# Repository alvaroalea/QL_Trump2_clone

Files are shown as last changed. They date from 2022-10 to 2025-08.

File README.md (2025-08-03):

# SINCLAIR QL Trump Card V2 disk interface

(C) 2022 Alvaro Alea Fernandez

License under: CERN Open Hardware Licence Version 2 - Strongly Reciprocal

https://ohwr.org/cern_ohl_s_v2.txt

Available in the market in 4 ways, 0K, 256Kb/ACE, 512Kb, 768Kb and Treo (256Kb aditional).

Only 0Kb has been tested.

Check the readme in the GAL folder, up to now, I only be able to make it work without RAM.

# Technical Info

## Components to use

### 4040
We found that not all manufacturer made CD4040 or 74HC4040 in the same way, and some made counter with rise-edge of clock, and some with falling-edge.

The trump card need falling edge or will mess with the refresh cycle and do not work.

The eprom/gal programer TL-866 II+ has a function to test TLL chips, but fail to detect it and consider valid both variants.

We have include the file 4040-test.lgc with a custom test that when load on the programmer allow to detect valid 74HC4040 variants. (best to use 74HC4040 that CD4040)

### RAM Chips
Trump Card use 514256 Ram chips, this is 4bits x 256K (1Mbit) Dinamic RAM.

Trump Card use a special refresh mode of this chips called hidden refresh, but not all manufacturer implement in tha same way.

Has been reported that Texas Instrument TMS44C256 are not valid and will cause errors on boot.

Motorola (MCM514256) Siemens (HYB514256) and OKI (MSM514256) has been reported to work

Toshiba (TC514256) and GoldStart (GM71C4256) al also valid acording to datasheet, but not tested.

The trump card schematic used 0 wait state ram, even in the refresh cycle, and for that speed of the dram shall be between 70 and 100ns, 120ns or slower are not valid.

HOLD

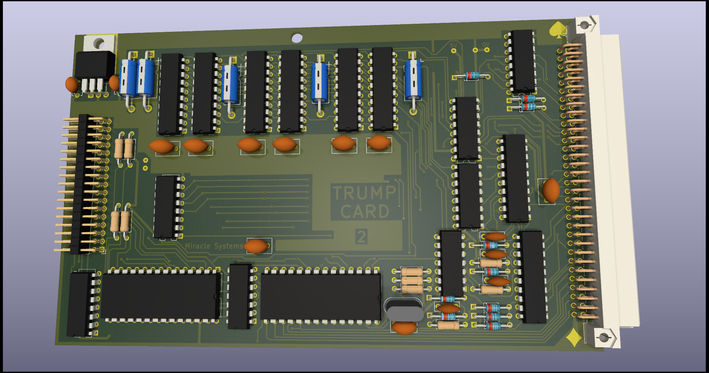
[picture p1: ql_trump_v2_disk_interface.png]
 

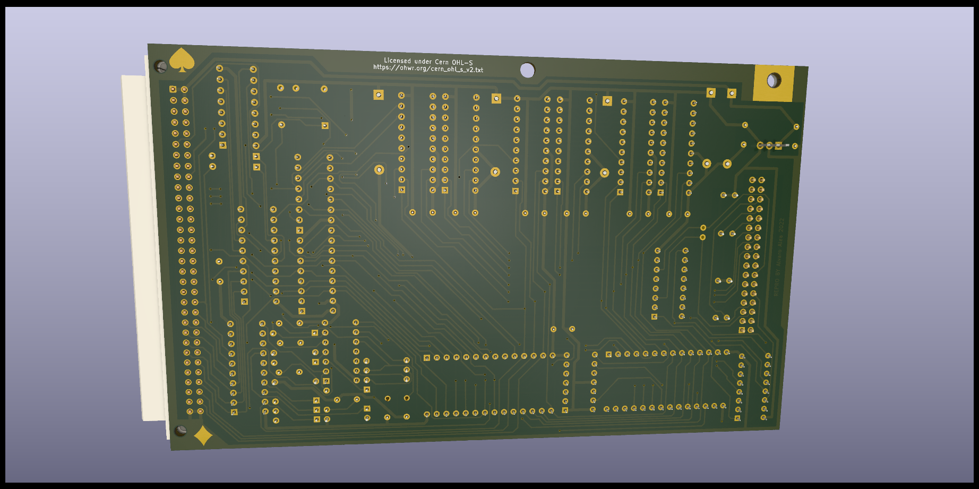
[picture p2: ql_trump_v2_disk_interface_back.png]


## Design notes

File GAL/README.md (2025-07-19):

# GAL Equations and JEDEC files

Trump Card contains 2 programable logic chips for several functions:
* Chip 1 is in charge of the I/O and Rom mapping, incorporate the mechanism to pagged in and out ROM and RAM in 0xC0000 on boot to allow JS ROM to start.
* Chip 2 is in charge of the RAS/CAS generation and other signals for the RAM chips.

In the original cards, both chips are of type PAL16L8, that is obsolete nowdays.

There is only 1 version of the Chip 1, and have a sticker with "1V4"

There is 2 diferent version of Chip 1, one for Trump Card 1 (with 24 RAM chips) labeled "2V2" and another for Trump Card 2 (6 RAM chips) labeled "2V4"

## Tetroid

This directory there is the equations shared by Tetroid and others in several places of internet.

Chip 1 is know to work if burn in a GAL16V8 chip, included JED files of the TC1, TC2 and Tetroid version, that are equal when disasembled.

Chip 2 for TC1 include dump and GALASM source.

Chip 2 for TC2 include JED for GAL and PAL, but is know that only the PAL work.

## only_minerva

My own version of the equations of the chip 1, intended to be used in a board without RAM with external RAM expansion.

This version only work with Minerva ROM, because it lack the pagging mechanism needed to boot in a JS ROM, this version is save to use with 768Kb external expansion, to achive the 892Kb (maximun RAM in a QL)

Include the Winculp source.

## wip

The Work-In-Progress ecuations

Chip 1 version with the pagging mechanish that work in JS and Minerva Roms. Miracle sell serveral version of the card with diferent memory configurations, its not clear if the ecuations of the chips are the same in all version, but in my test I need to develop version for each memory configuration. Source is in GALASM format

Only 0Kb has been tested, this GAL is Safe to use with any external RAM expansion up to 512 Kb, can also be used my own +256Kb RAM expansion if wire the P13 of GAL1 to the RAM expansion Card.

Chip 2 are still not working, but include some test in GALASM and Winculp formats, and some notes.

# Technical Details

Our guest of the timmings need for access memory of the trump card are as per next graphics:

Normal read cycle
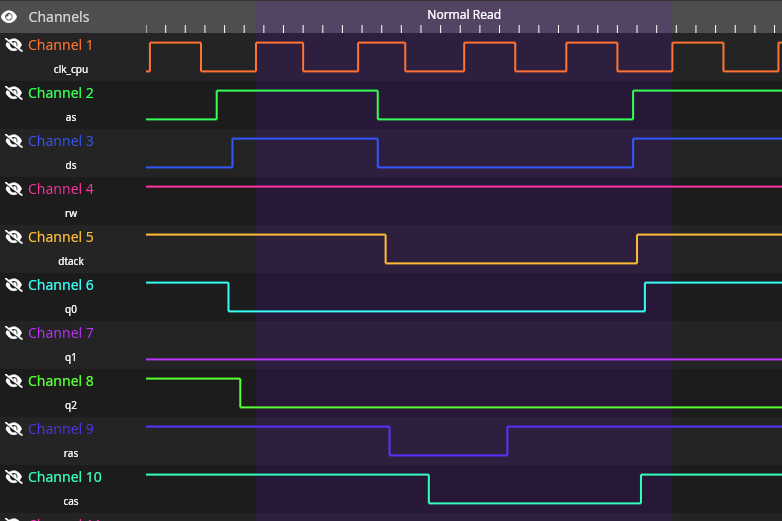
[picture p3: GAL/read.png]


A refresh cycle using cas-before-ras method
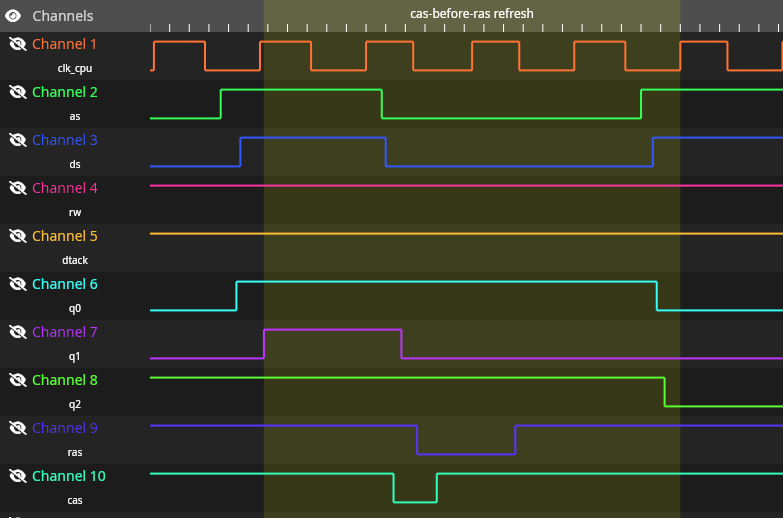
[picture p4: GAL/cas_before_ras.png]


A read cycle plus a hidden refresh using a second RAS pulse.
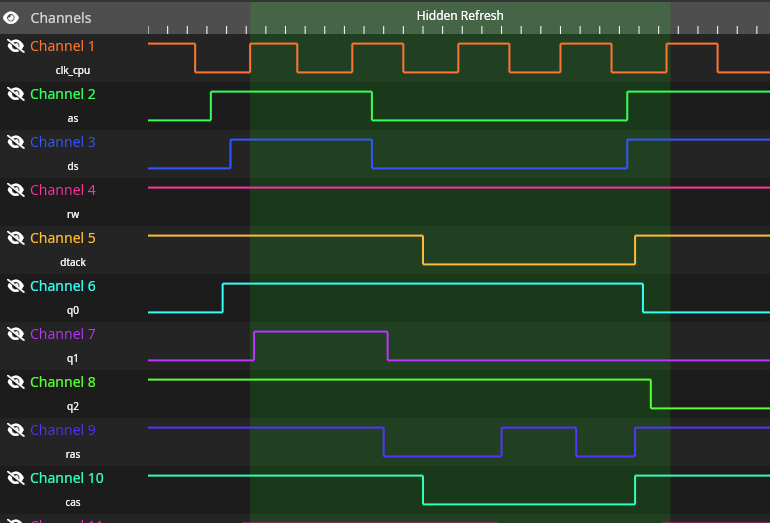
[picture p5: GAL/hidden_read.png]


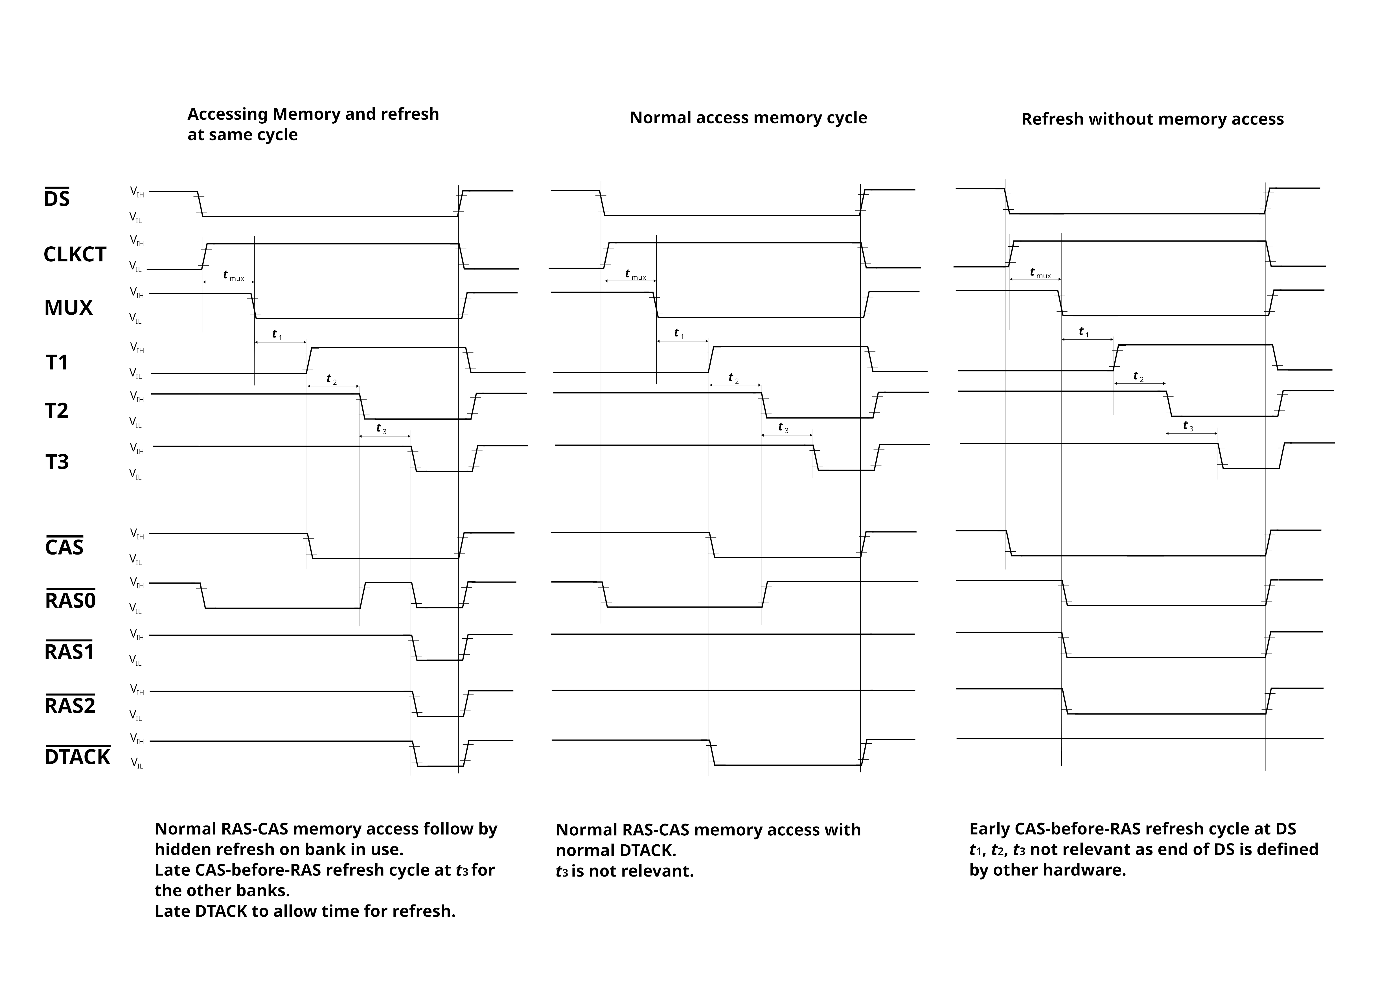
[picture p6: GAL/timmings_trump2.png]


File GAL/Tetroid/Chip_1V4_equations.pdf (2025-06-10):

### Chip 1V4_TI PAL16L8

Inputs :

DSL=1; A19=2; A18=3; A17=4; A16=5; A15=6; RESETCPUL=7; A14=8; A13=9; MUX=11

Outputs :

DSMCL=12; CLKCT=14; MA8=15; CSFDCL=17; CS175L=18; ROMCSL=19

Storage :

P13=13; P16=16

Equations :

/ROMCSL = /A19 * /DSL * /A18 * /A17 * A16 * /A15

+ A19 * /DSL * A18 * /A17 * /A16 * /A15 * /P13

/CS175L = /A19 * /DSL * /A18 * /A17 * A16 * A15 * A14 * A13

/CSFDCL = /A19 * /DSL * /A18 * /A17 * A16 * A15 * A14 * /A13

/P16 = /A19 * /DSL * /A18 * /A17 * A16 * /A15 * /A14

+ /P16 * RESETCPUL

/MA8 = A17 * MUX

+ A16 * /MUX

/CLKCT = DSL

/P13 = /A19 * /DSL * /A18 * /A17 * /A16 * P16 * A15 * A14

+ A19 * RESETCPUL * /P13

+ A18 * RESETCPUL * /P13

+ A17 * RESETCPUL * /P13

+ /A16 * RESETCPUL * /P13

+ A15 * RESETCPUL * /P13

+ DSL * RESETCPUL * /P13

/DSMCL = /A19 * /A18 * /A17 * /A16

+ /A19 * /A18 * /A17 * A16 * A15 * /A14

+ /A19 * /A18 * A17

+ A19 * A18 * /A17 * /A16 * A15 * /P13

+ A19 * A18 * /A17 * A16 * /P13

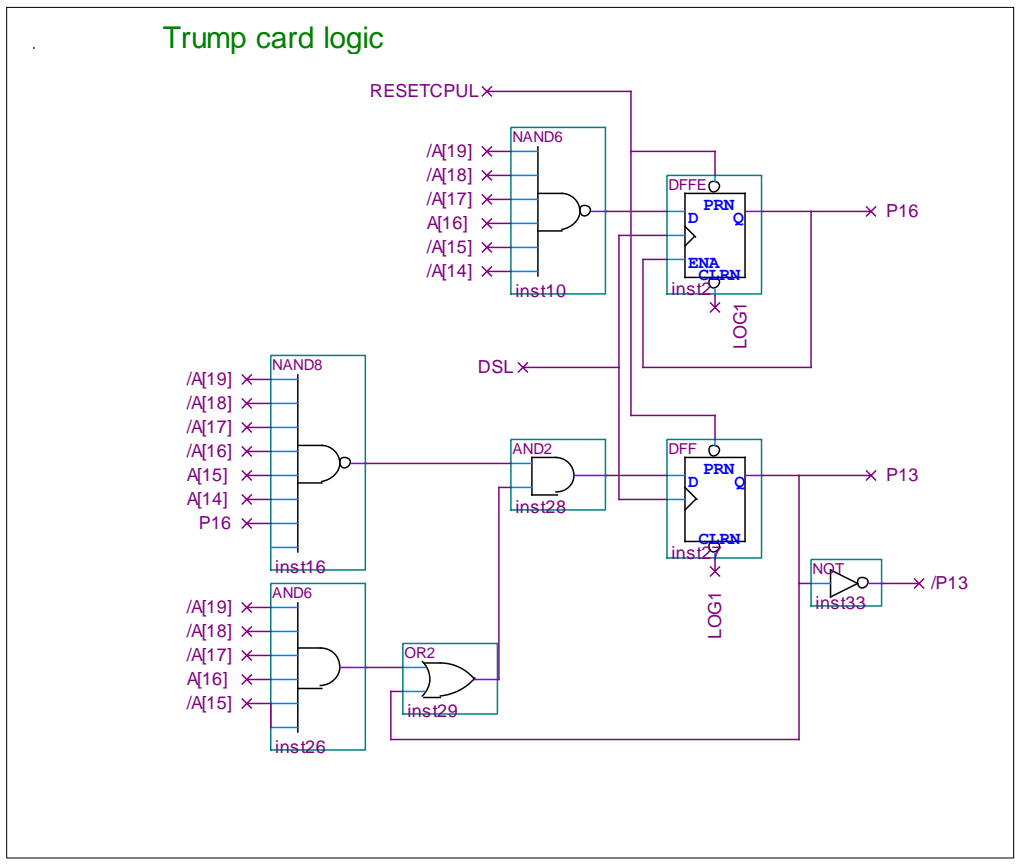
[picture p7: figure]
PRN; CLRN; ENA; DFFE; inst2; NAND6; inst10; NAND8; inst16; AND6; inst26; PRN Q; DFF; inst27; AND2; inst28; inst29; NOT; inst33; RESETCPUL; DSL; LOG¹ LOG¹; Trump card logic

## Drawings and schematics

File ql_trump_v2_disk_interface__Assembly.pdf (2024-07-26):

A

A

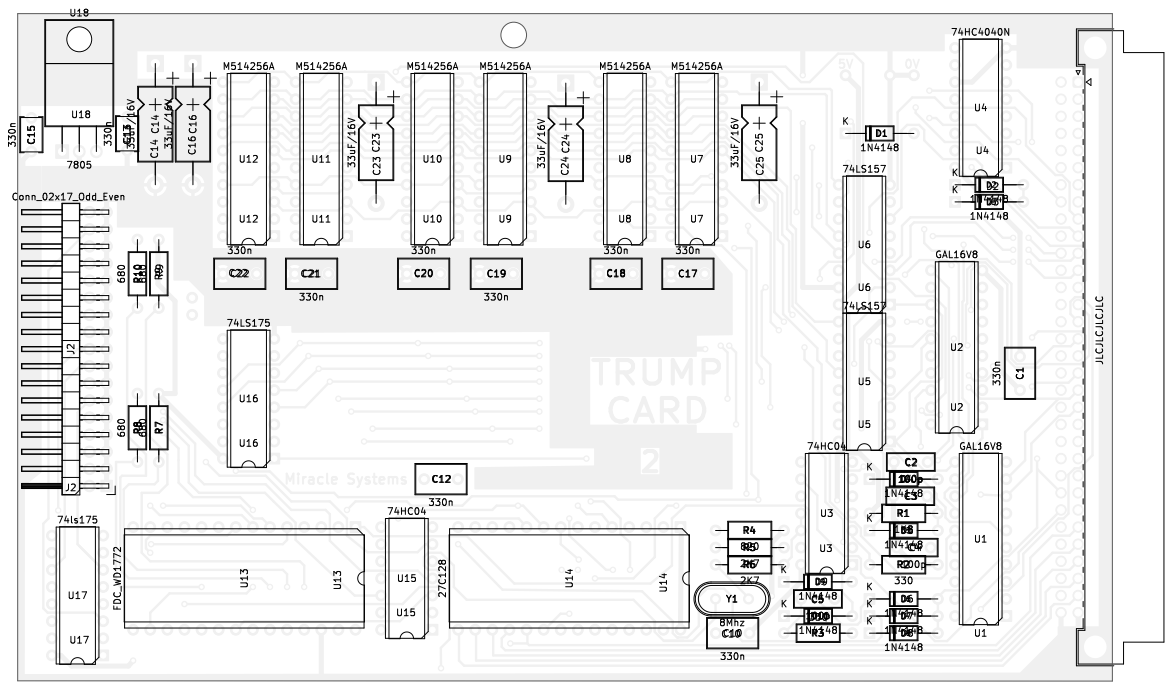
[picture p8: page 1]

A

A

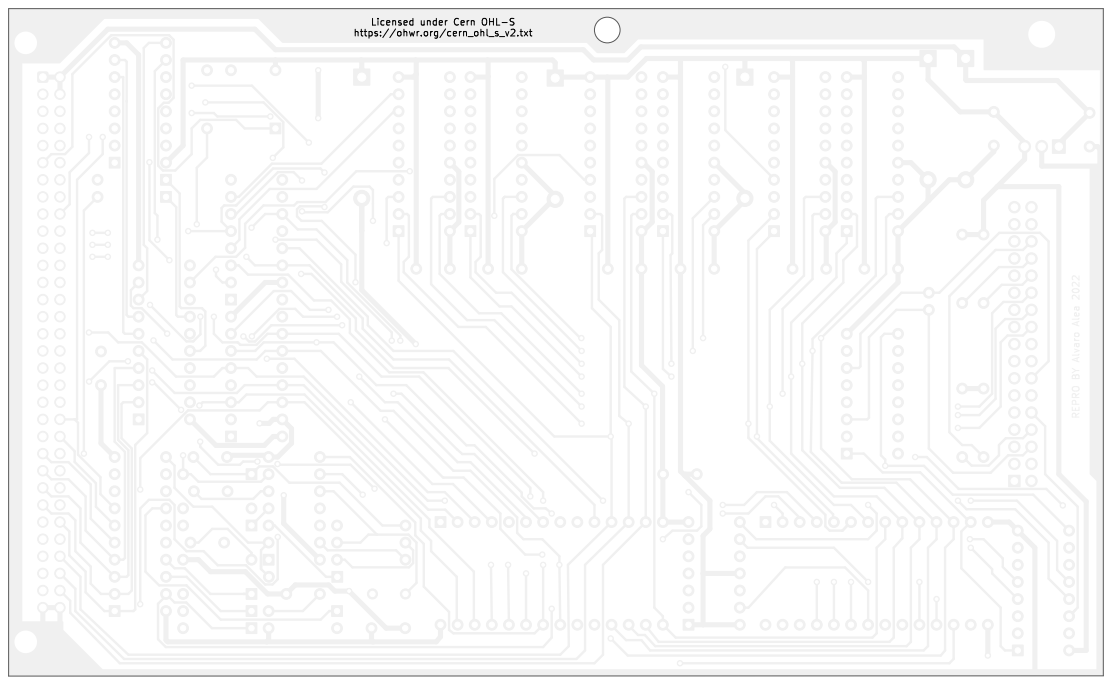
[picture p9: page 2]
https://ohwr.org/cern_ohl_s_v2.txt 1; D Date: 2022-10-01 KiCad; E.D.A. 8.0.3 Size: A4; Rev: 01; Id: 1/1 Title: Trump Card 2 (Clone) File: ql_trump_v2_disk_interface.kicad_pcb Sheet: Repro; by Alvaro Alea; Fdz. Disk; Interface; for Sinclair

Licensed under Cern OHL-S

REPRO BY Alvaro Alea 2022

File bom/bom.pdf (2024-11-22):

Trump Card 2 (Clone) | Rev: 01
Trump Card 2 (Clone) BOM | file:///home/alvaro/kicadprojects/github/QL_Trump2_clone/bom/ibom.html

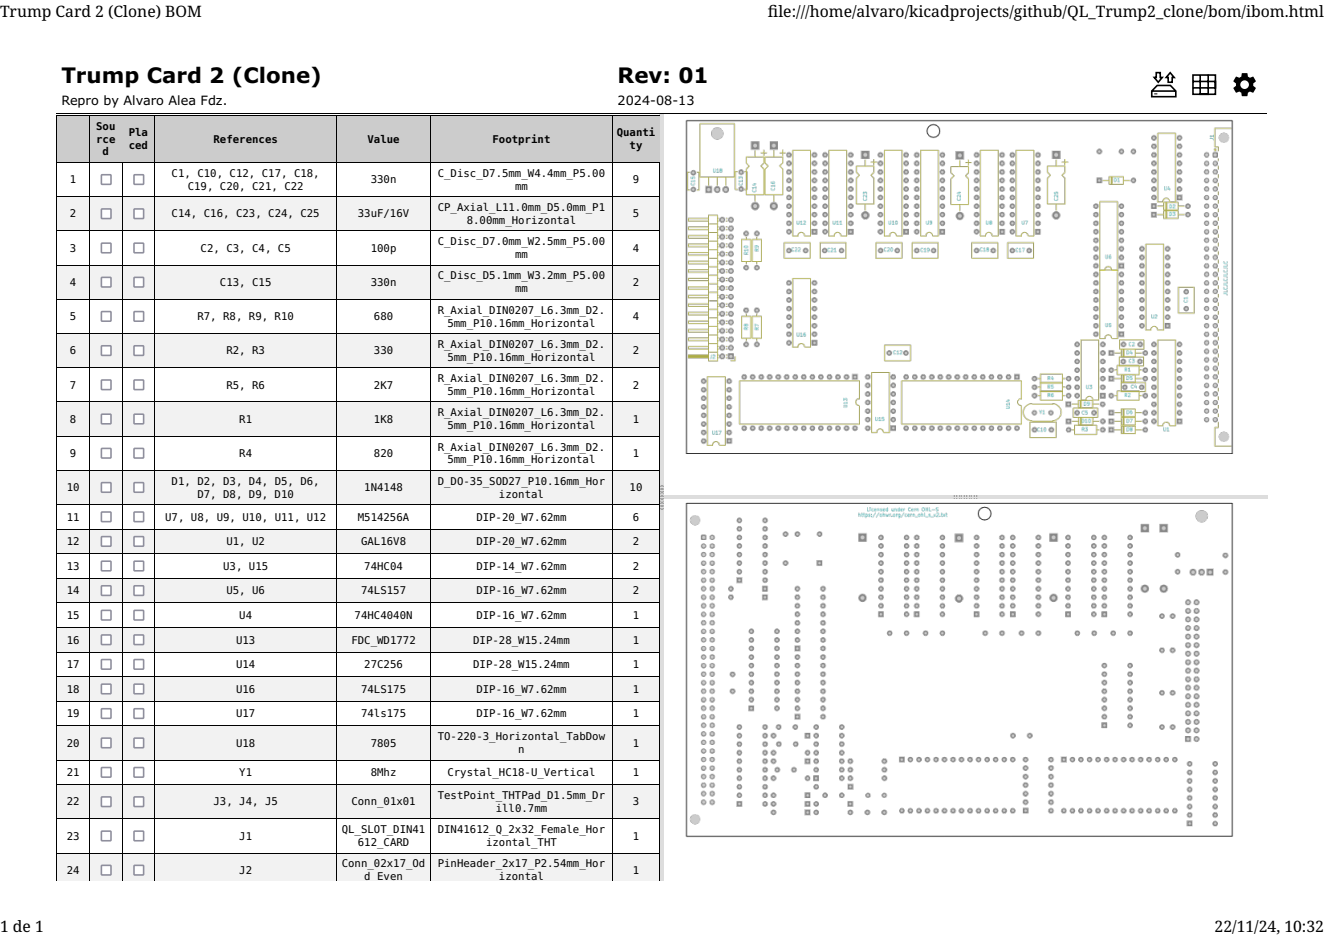
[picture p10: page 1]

Sou rce d | Pla ced | References | Value | Footprint | Quanti ty

1 | | | C1, C10, C12, C17, C18, C19, C20, C21, C22 | 330n | C_Disc_D7.5mm_W4.4mm_P5.00 mm | 9

2 | | | C14, C16, C23, C24, C25 | 33uF/16V | CP_Axial_L11.0mm_D5.0mm_P1 8.00mm_Horizontal | 5

3 | | | C2, C3, C4, C5 | 100p | C_Disc_D7.0mm_W2.5mm_P5.00 mm | 4

4 | | | C13, C15 | 330n | C_Disc_D5.1mm_W3.2mm_P5.00 mm | 2

5 | | | R7, R8, R9, R10 | 680 | R_Axial_DIN0207_L6.3mm_D2. 5mm_P10.16mm_Horizontal | 4

6 | | | R2, R3 | 330 | R_Axial_DIN0207_L6.3mm_D2. 5mm_P10.16mm_Horizontal | 2

7 | | | R5, R6 | 2K7 | R_Axial_DIN0207_L6.3mm_D2. 5mm_P10.16mm_Horizontal | 2

8 | | | R1 | 1K8 | R_Axial_DIN0207_L6.3mm_D2. 5mm_P10.16mm_Horizontal | 1

9 | | | R4 | 820 | R_Axial_DIN0207_L6.3mm_D2. 5mm_P10.16mm_Horizontal | 1

10 | | | D1, D2, D3, D4, D5, D6, D7, D8, D9, D10 | 1N4148 | D_DO-35_SOD27_P10.16mm_Hor izontal | 10

11 | | | U7, U8, U9, U10, U11, U12 | M514256A | DIP-20_W7.62mm | 6

12 | | | U1, U2 | GAL16V8 | DIP-20_W7.62mm | 2

13 | | | U3, U15 | 74HC04 | DIP-14_W7.62mm | 2

14 | | | U5, U6 | 74LS157 | DIP-16_W7.62mm | 2

15 | | | U4 | 74HC4040N | DIP-16_W7.62mm | 1

16 | | | U13 | FDC_WD1772 | DIP-28_W15.24mm | 1

17 | | | U14 | 27C256 | DIP-28_W15.24mm | 1

18 | | | U16 | 74LS175 | DIP-16_W7.62mm | 1

19 | | | U17 | 74ls175 | DIP-16_W7.62mm | 1

20 | | | U18 | 7805 | TO-220-3_Horizontal_TabDow n | 1

21 | | | Y1 | 8Mhz | Crystal_HC18-U_Vertical | 1

22 | | | J3, J4, J5 | Conn_01x01 | TestPoint_THTPad_D1.5mm_Dr ill0.7mm | 3

23 | | | J1 | QL_SLOT_DIN41 612_CARD | DIN41612_Q_2x32_Female_Hor izontal_THT | 1

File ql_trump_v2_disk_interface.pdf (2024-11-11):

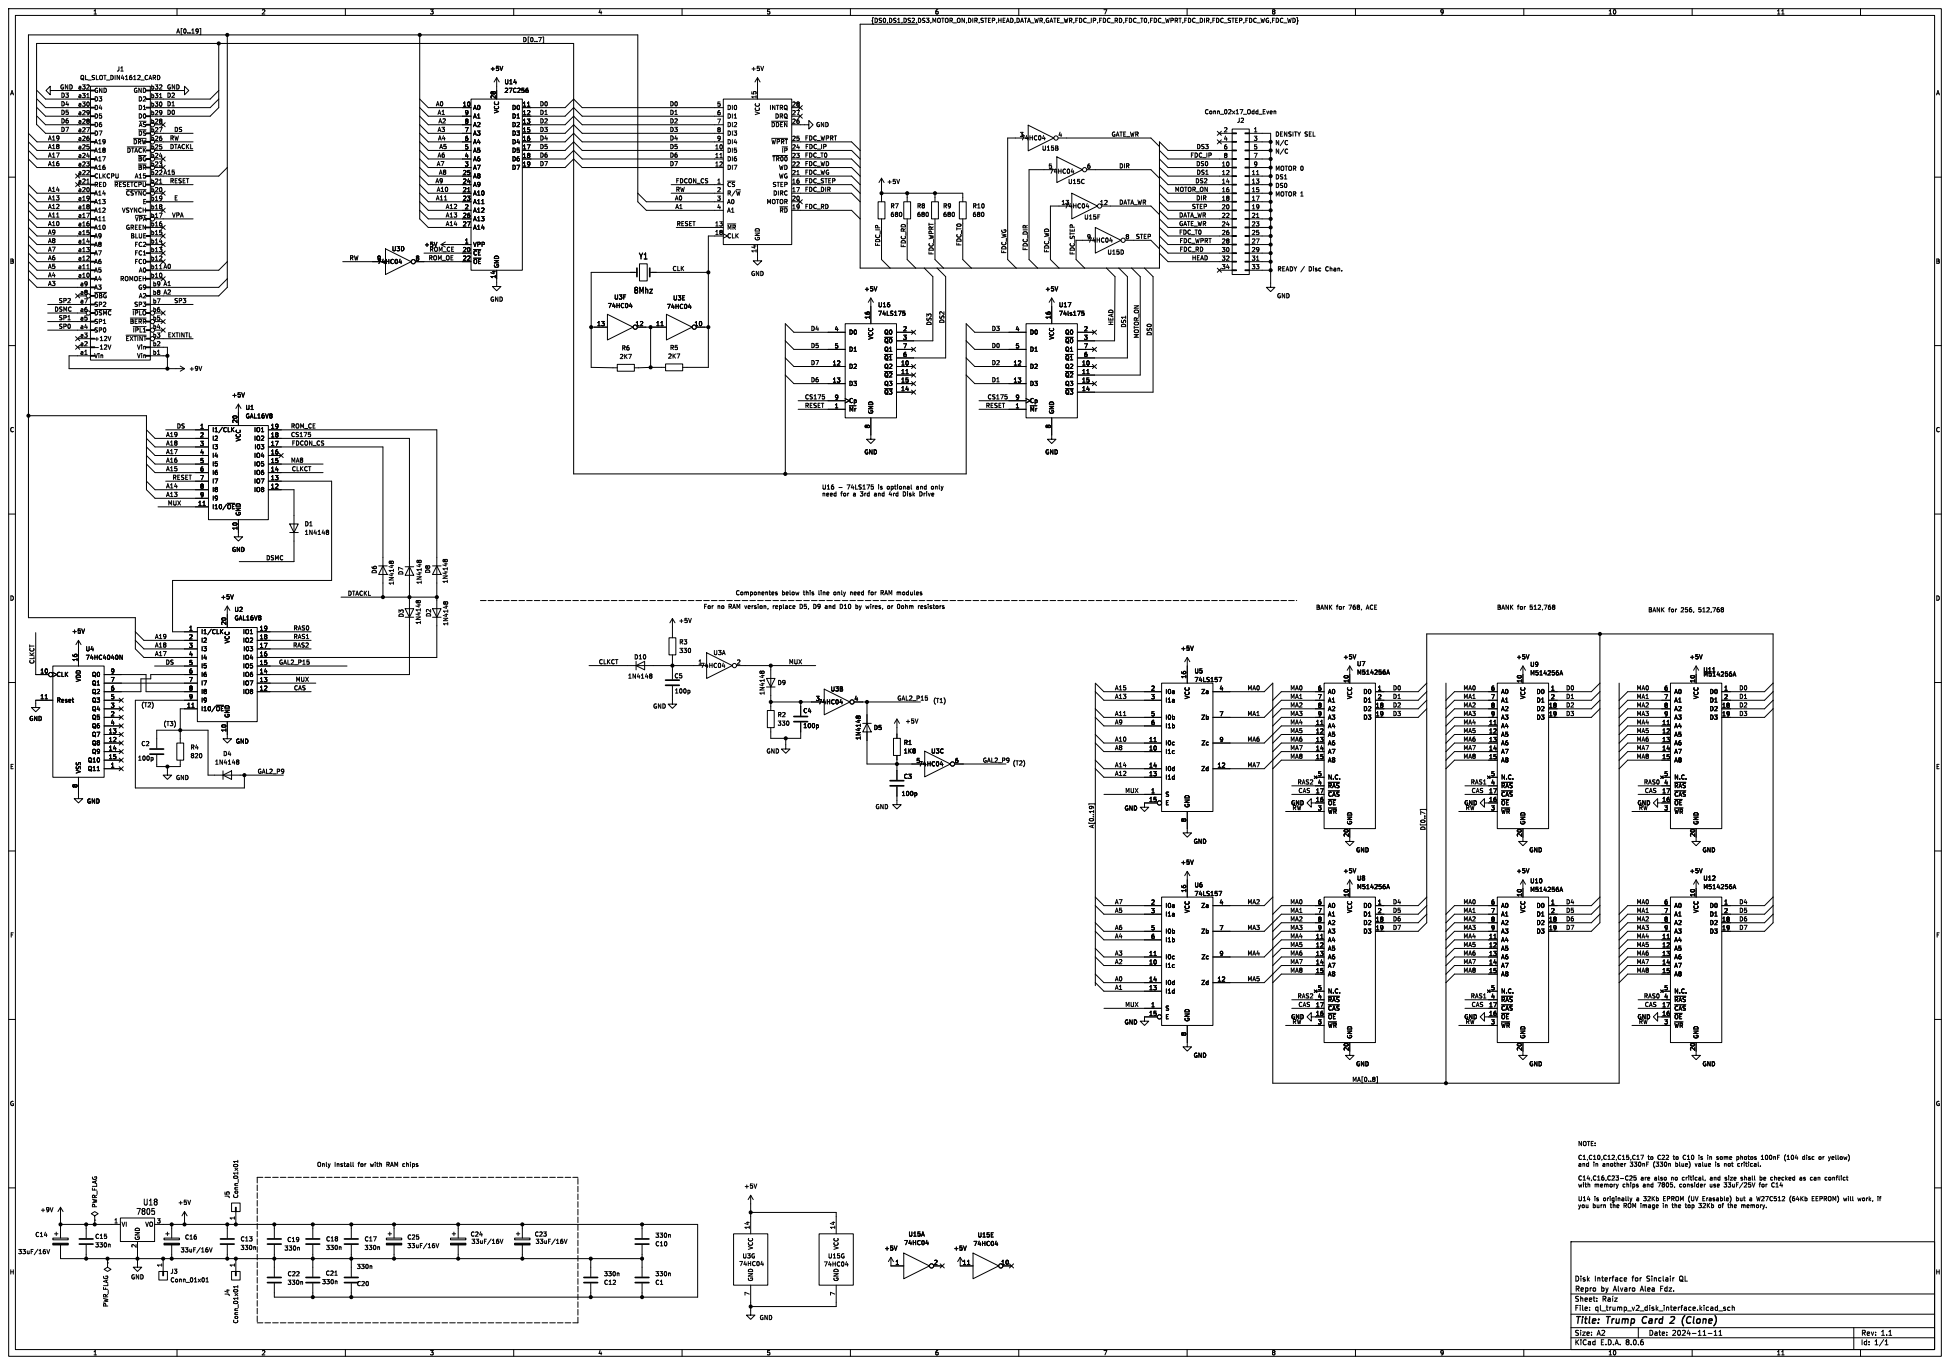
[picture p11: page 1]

BANK for 256, 512,768 BANK for 768, ACE

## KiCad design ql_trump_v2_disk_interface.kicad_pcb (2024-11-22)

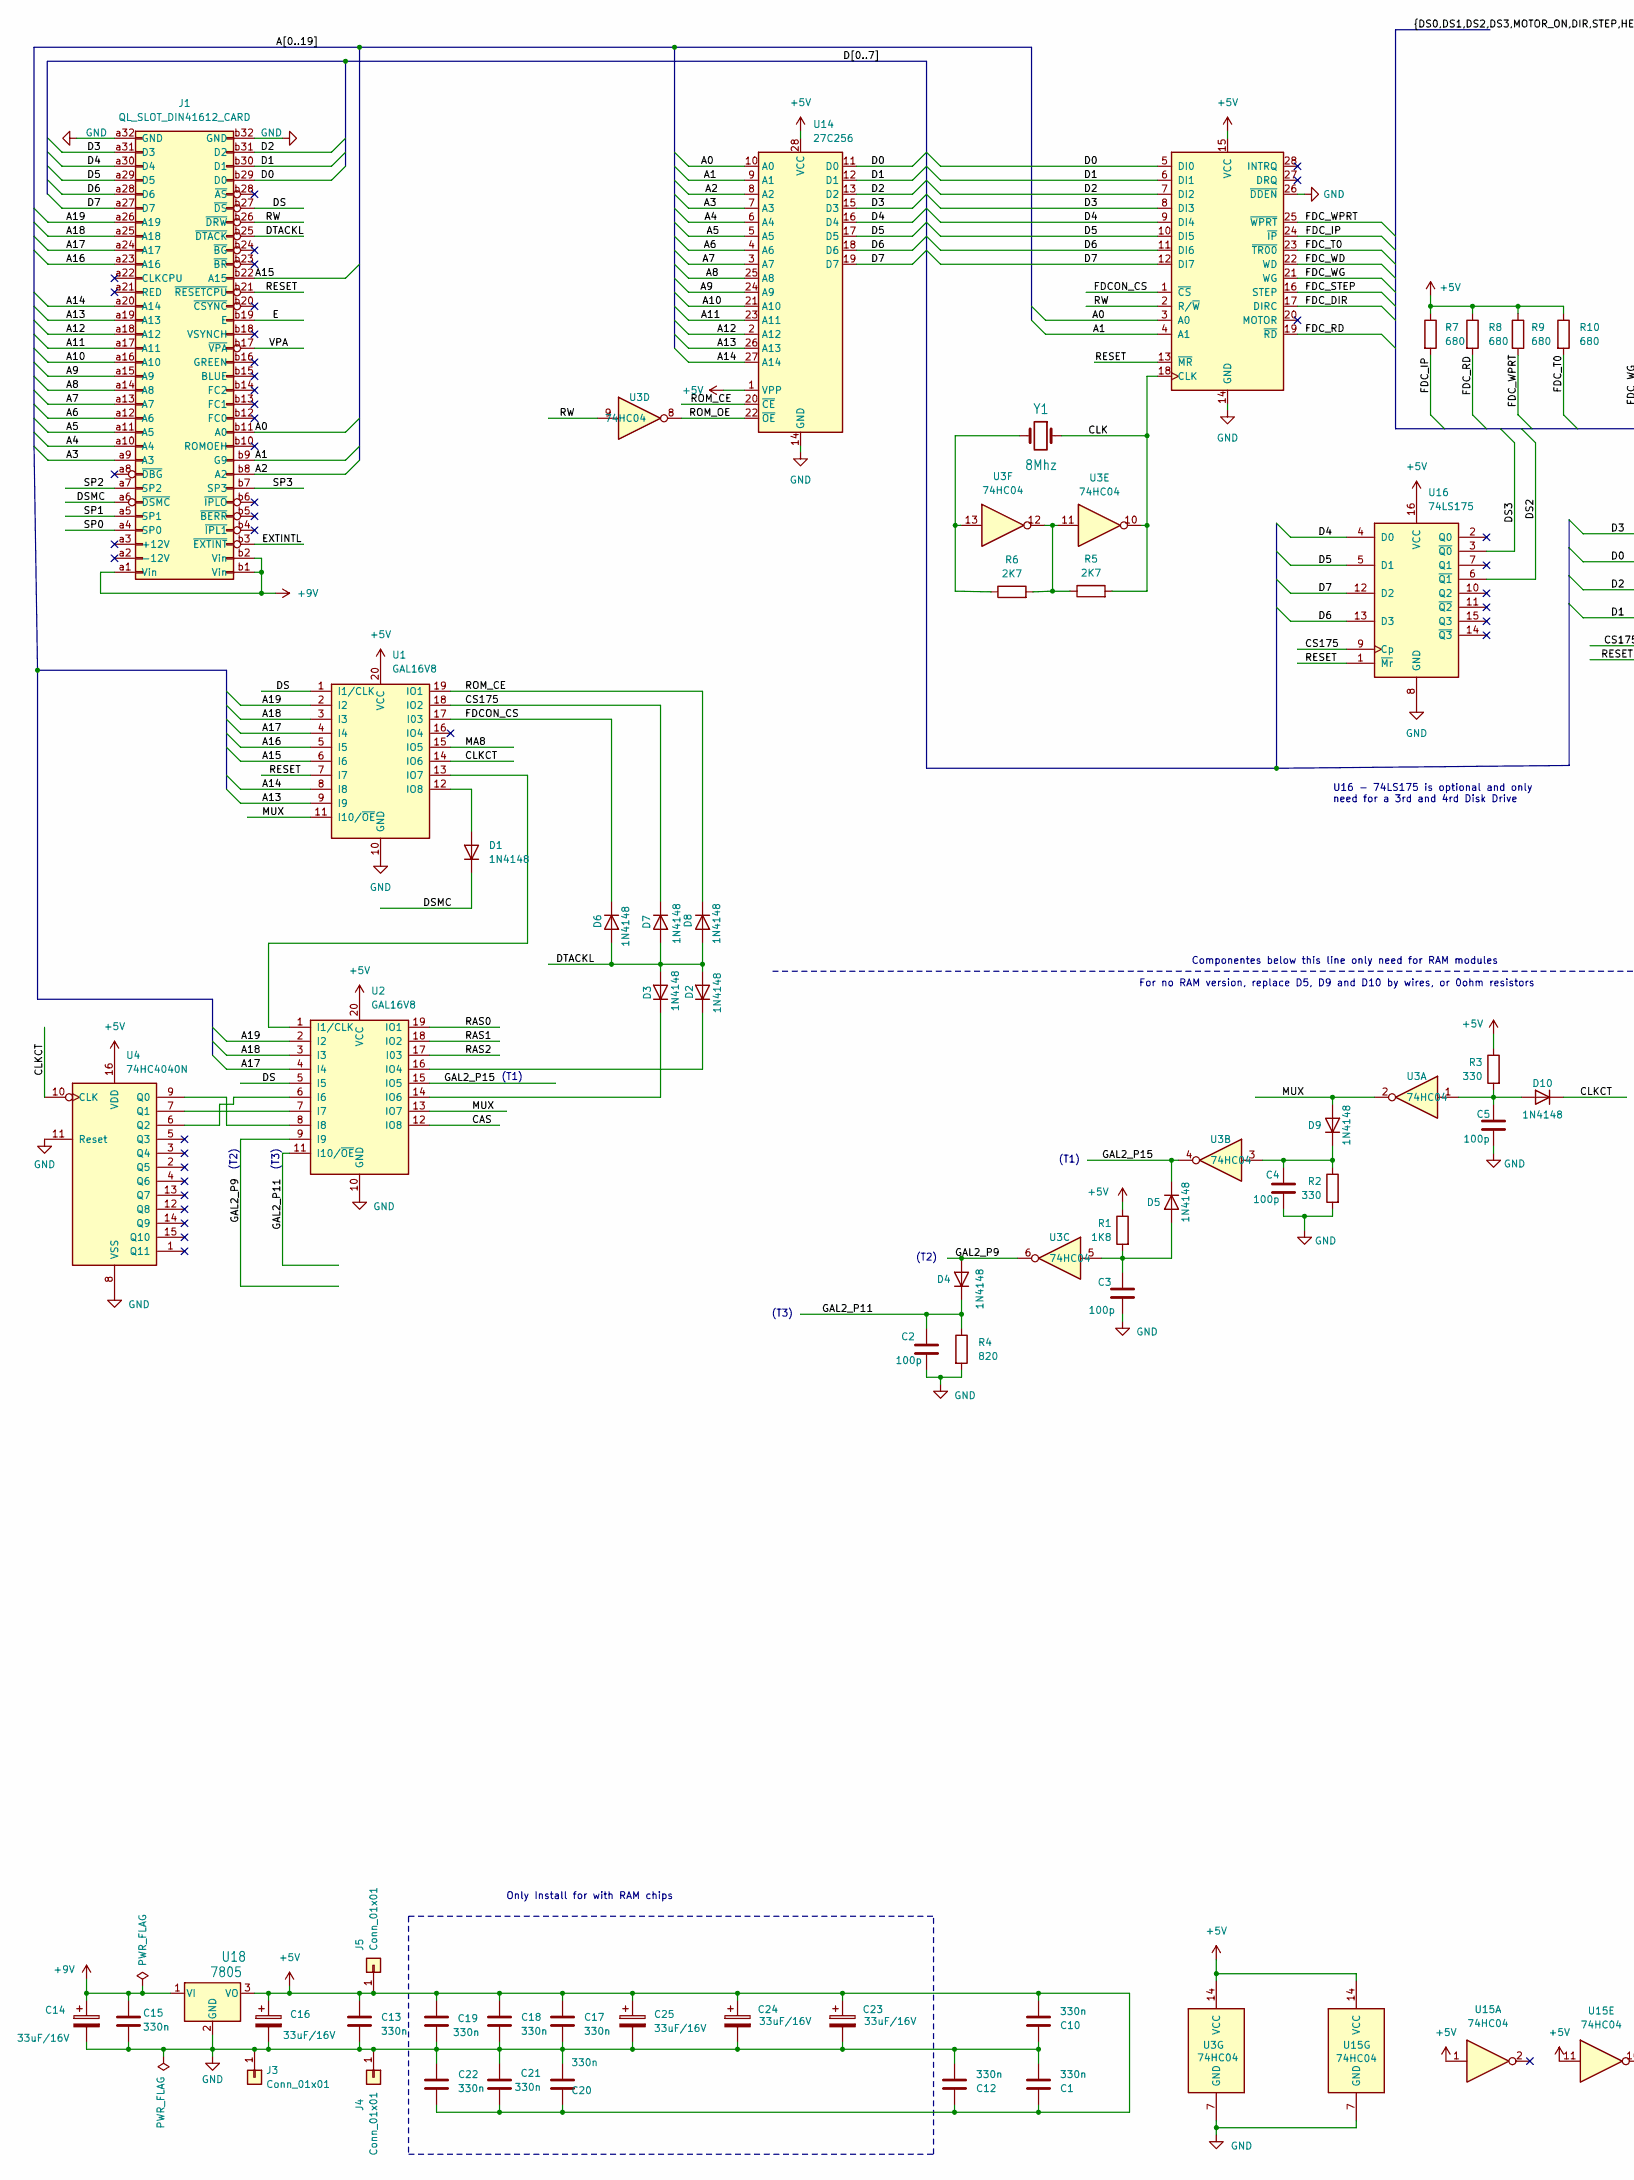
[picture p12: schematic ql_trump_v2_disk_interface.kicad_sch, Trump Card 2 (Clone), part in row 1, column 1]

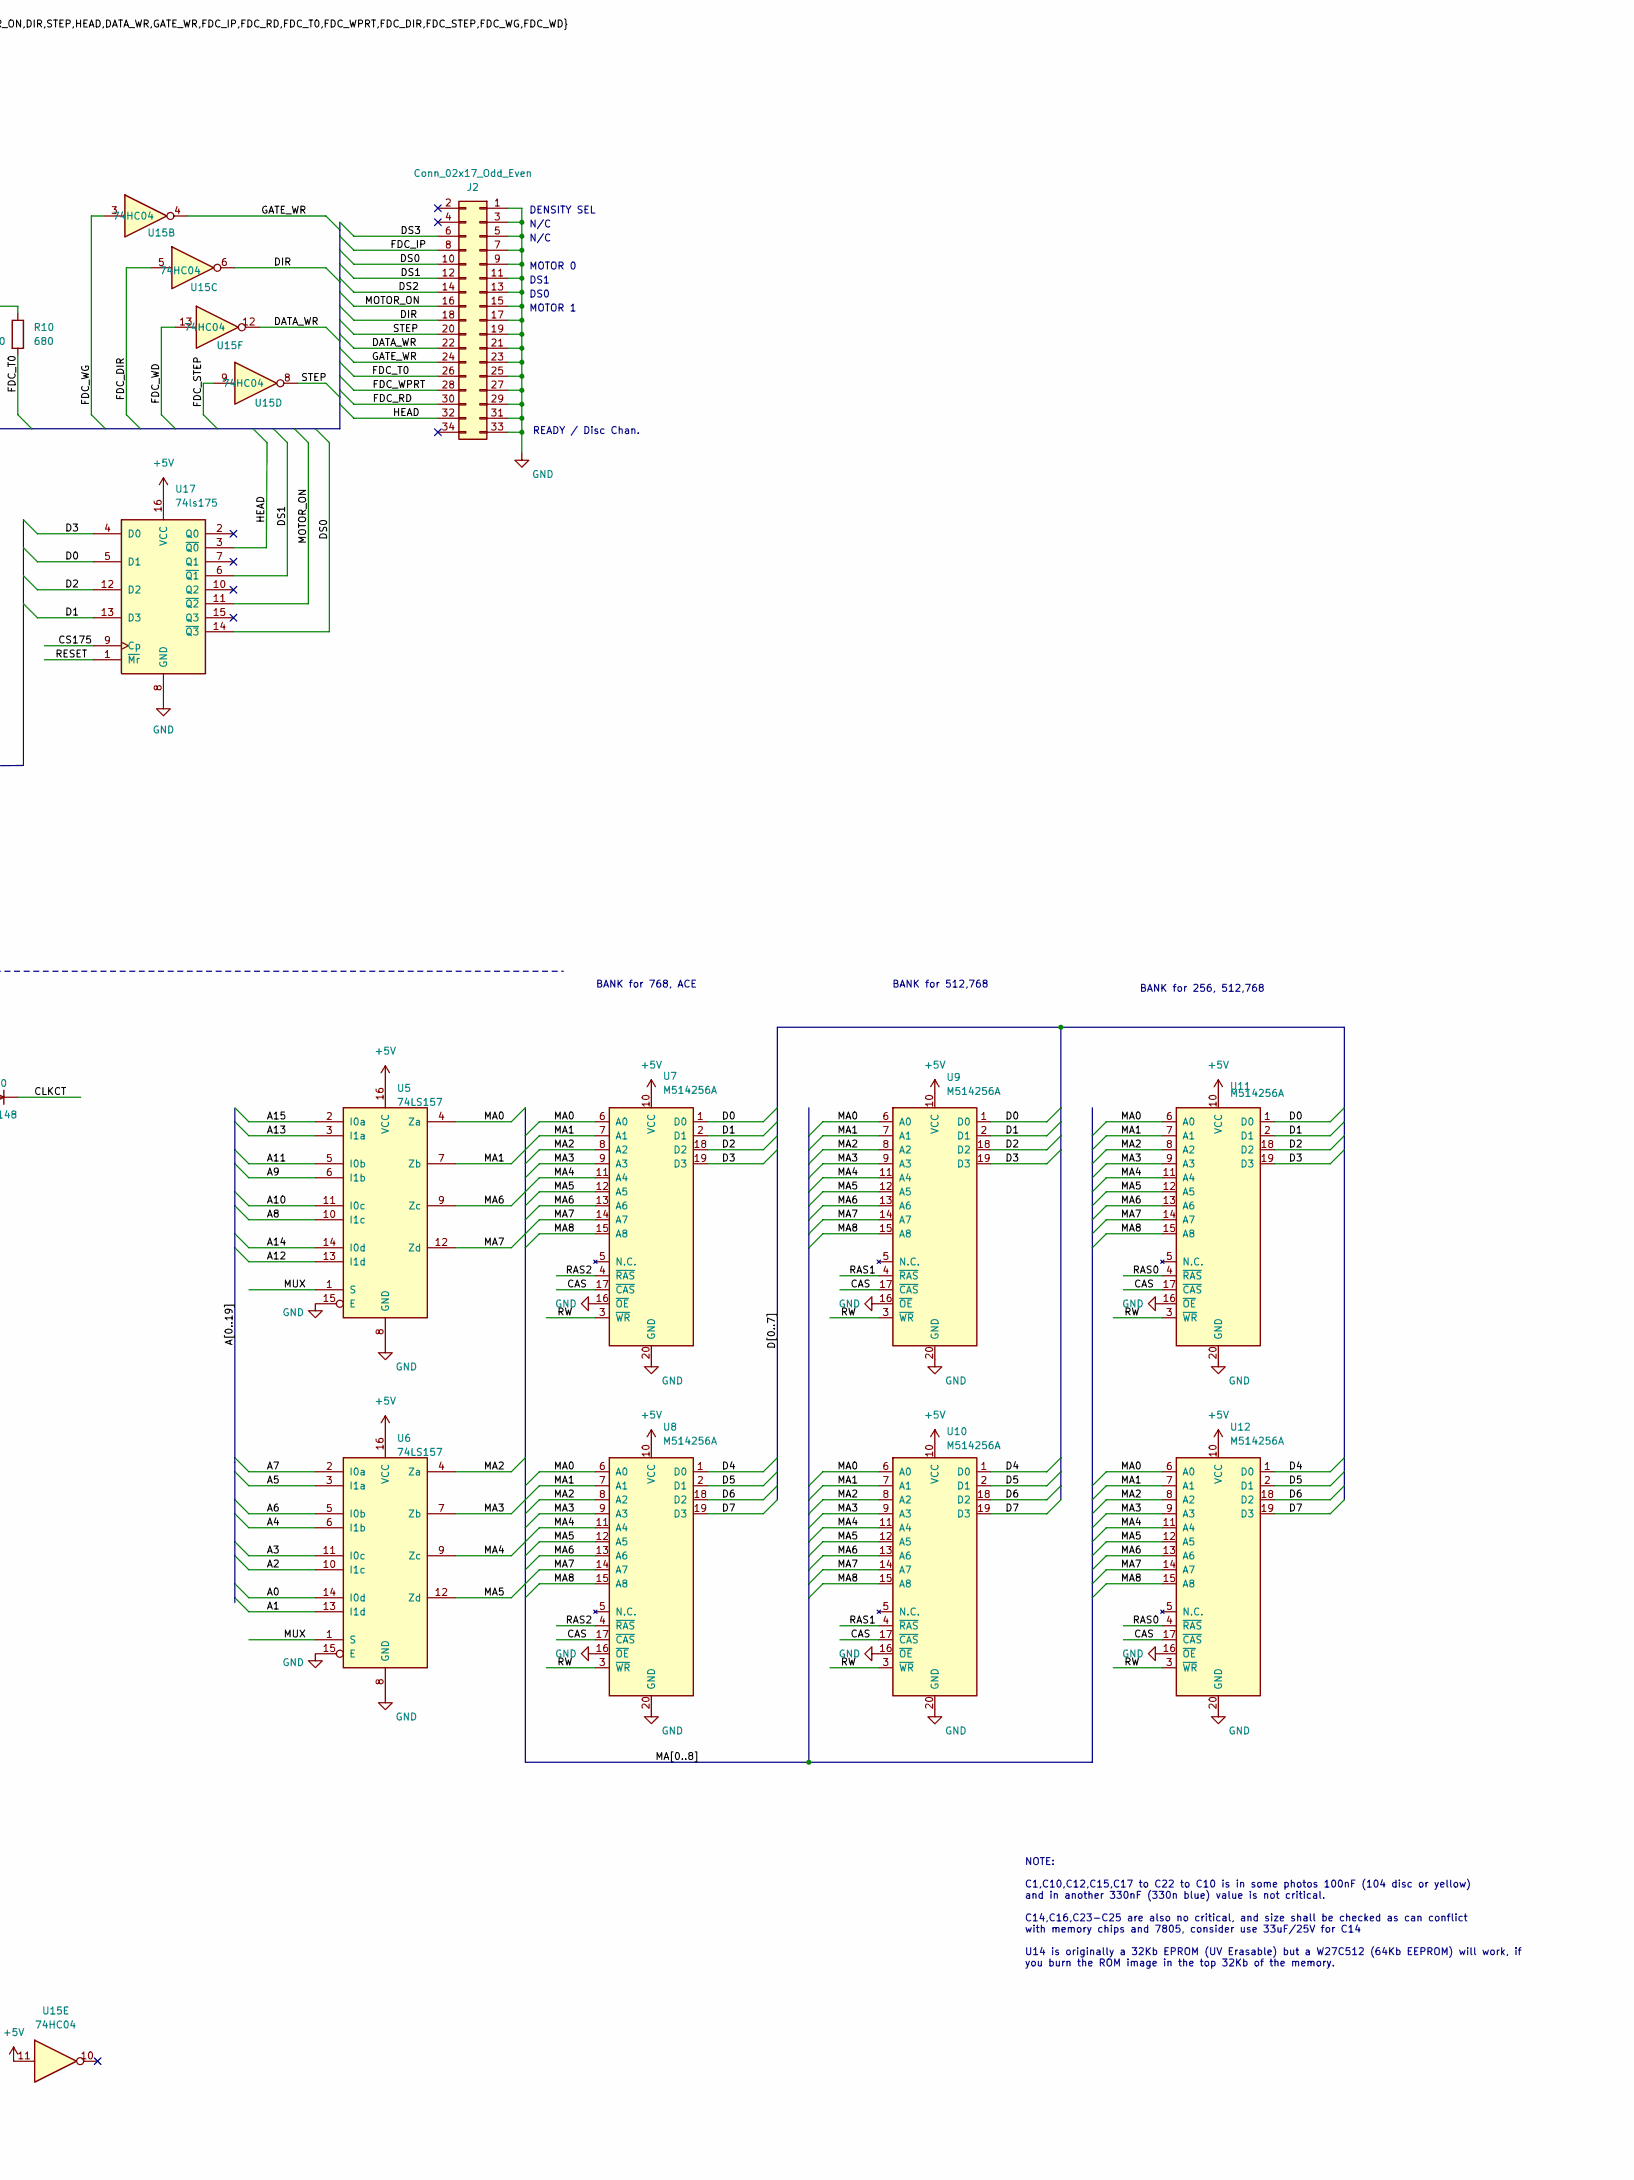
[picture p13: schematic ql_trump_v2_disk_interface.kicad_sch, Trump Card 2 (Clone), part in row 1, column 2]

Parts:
C1, C10, C12, C17, C18, C19, C20, C21, C22: 330n; C_Disc_D7.5mm_W4.4mm_P5.00mm
C2, C3, C4, C5: 100p; C_Disc_D7.0mm_W2.5mm_P5.00mm
C13, C15: 330n; C_Disc_D5.1mm_W3.2mm_P5.00mm
C14, C16, C23, C24, C25: 33uF/16V; CP_Axial_L11.0mm_D5.0mm_P18.00mm_Horizontal
D1, D2, D3, D4, D5, D6, D7, D8, D9, D10: 1N4148; D_DO-35_SOD27_P10.16mm_Horizontal
J1: QL_SLOT_DIN41612_CARD; DIN41612_Q_2x32_Female_Horizontal_THT
J2: Conn_02x17_Odd_Even; PinHeader_2x17_P2.54mm_Horizontal
J3, J4, J5: Conn_01x01; TestPoint_THTPad_D1.5mm_Drill0.7mm
R1: 1K8; R_Axial_DIN0207_L6.3mm_D2.5mm_P10.16mm_Horizontal
R2, R3: 330; R_Axial_DIN0207_L6.3mm_D2.5mm_P10.16mm_Horizontal
R4: 820; R_Axial_DIN0207_L6.3mm_D2.5mm_P10.16mm_Horizontal
R5, R6: 2K7; R_Axial_DIN0207_L6.3mm_D2.5mm_P10.16mm_Horizontal
R7, R8, R9, R10: 680; R_Axial_DIN0207_L6.3mm_D2.5mm_P10.16mm_Horizontal
U1, U2: GAL16V8; DIP-20_W7.62mm
U3, U15: 74HC04; DIP-14_W7.62mm
U4: 74HC4040N; DIP-16_W7.62mm
U5, U6: 74LS157; DIP-16_W7.62mm
U7, U8, U9, U10, U11, U12: M514256A; DIP-20_W7.62mm
U13: FDC_WD1772; DIP-28_W15.24mm
U14: 27C256; DIP-28_W15.24mm
U16: 74LS175; DIP-16_W7.62mm
U17: 74ls175; DIP-16_W7.62mm
U18: 7805; TO-220-3_Horizontal_TabDown
Y1: 8Mhz; Crystal_HC18-U_Vertical

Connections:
+5V: C1.1, C10.2, C12.1, C13.1, C16.1, C17.1, C18.1, C19.2, C20.1, C21.2, C22.1, C23.1, C24.1, C25.1, J5.1, R1.1, R3.1, R7.1, R8.1, R9.1, R10.1, U1.20 (VCC), U2.20 (VCC), U3.14 (VCC), U4.16 (VDD), U5.16 (VCC), U6.16 (VCC), U7.10 (VCC), U8.10 (VCC), U9.10 (VCC), U10.10 (VCC), U11.10 (VCC), U12.10 (VCC), U13.15 (VCC), U14.1 (VPP), U14.28 (VCC), U15.1, U15.11, U15.14 (VCC), U16.16 (VCC), U17.16 (VCC), U18.3 (VO)
+9V: C14.1, C15.1, J1.a1 (Vin), J1.b1 (Vin), J1.b2 (Vin), U18.1 (VI)
/A0: J1.b11 (A0), U6.14 (I0d), U13.3 (A0), U14.10 (A0)
/A1: J1.b9 (G9), U6.13 (I1d), U13.4 (A1), U14.9 (A1)
/A2: J1.b8 (A2), U6.10 (I1c), U14.8 (A2)
/A3: J1.a9 (A3), U6.11 (I0c), U14.7 (A3)
/A4: J1.a10 (A4), U6.6 (I1b), U14.6 (A4)
/A5: J1.a11 (A5), U6.3 (I1a), U14.5 (A5)
/A6: J1.a12 (A6), U6.5 (I0b), U14.4 (A6)
/A7: J1.a13 (A7), U6.2 (I0a), U14.3 (A7)
/A8: J1.a14 (A8), U5.10 (I1c), U14.25 (A8)
/A9: J1.a15 (A9), U5.6 (I1b), U14.24 (A9)
/A10: J1.a16 (A10), U5.11 (I0c), U14.21 (A10)
/A11: J1.a17 (A11), U5.5 (I0b), U14.23 (A11)
/A12: J1.a18 (A12), U5.13 (I1d), U14.2 (A12)
/A13: J1.a19 (A13), U1.9 (I9), U5.3 (I1a), U14.26 (A13)
/A14: J1.a20 (A14), U1.8 (I8), U5.14 (I0d), U14.27 (A14)
/A15: J1.b22 (A15), U1.6 (I6), U5.2 (I0a)
/A16: J1.a23 (A16), U1.5 (I5)
/A17: J1.a24 (A17), U1.4 (I4), U2.4 (I4)
/A18: J1.a25 (A18), U1.3 (I3), U2.3 (I3)
/A19: J1.a26 (A19), U1.2 (I2), U2.2 (I2)
/CAS: U2.12 (IO8), U7.17 (~CAS), U8.17 (~CAS), U9.17 (~CAS), U10.17 (~CAS), U11.17 (~CAS), U12.17 (~CAS)
/CLK: R5.2, U3.10, U13.18 (CLK), Y1.1
/CLKCT: D10.1 (K), U1.14 (IO6), U4.10 (CLK)
/CS175: D7.1 (K), U1.18 (IO2), U16.9 (Cp), U17.9 (Cp)
/D0: J1.b29 (D0), U7.1 (D0), U9.1 (D0), U11.1 (D0), U13.5 (DI0), U14.11 (D0), U17.5 (D1)
/D1: J1.b30 (D1), U7.2 (D1), U9.2 (D1), U11.2 (D1), U13.6 (DI1), U14.12 (D1), U17.13 (D3)
/D2: J1.b31 (D2), U7.18 (D2), U9.18 (D2), U11.18 (D2), U13.7 (DI2), U14.13 (D2), U17.12 (D2)
/D3: J1.a31 (D3), U7.19 (D3), U9.19 (D3), U11.19 (D3), U13.8 (DI3), U14.15 (D3), U17.4 (D0)
/D4: J1.a30 (D4), U8.1 (D0), U10.1 (D0), U12.1 (D0), U13.9 (DI4), U14.16 (D4), U16.4 (D0)
/D5: J1.a29 (D5), U8.2 (D1), U10.2 (D1), U12.2 (D1), U13.10 (DI5), U14.17 (D5), U16.5 (D1)
/D6: J1.a28 (D6), U8.18 (D2), U10.18 (D2), U12.18 (D2), U13.11 (DI6), U14.18 (D6), U16.13 (D3)
/D7: J1.a27 (D7), U8.19 (D3), U10.19 (D3), U12.19 (D3), U13.12 (DI7), U14.19 (D7), U16.12 (D2)
/DATA_WR: J2.22, U15.12
/DIR: J2.18, U15.6
/DS: J1.b27 (~DS), U1.1 (I1/CLK), U2.5 (I5)
/DS0: J2.10, U17.14 (~Q3)
/DS1: J2.12, U17.6 (~Q1)
/DS2: J2.14, U16.6 (~Q1)
/DS3: J2.6, U16.3 (~Q0)
/DSMC: D1.1 (K), J1.a6 (~DSMC)
/DTACKL: D2.2 (A), D3.2 (A), D6.2 (A), D7.2 (A), D8.2 (A), J1.b25 (~DTACK)
/E: J1.b19 (E)
/EXTINTL: J1.b3 (~EXTINT)
/FDCON_CS: D6.1 (K), U1.17 (I03), U13.1 (~CS)
/FDC_DIR: U13.17 (DIRC), U15.5
/FDC_IP: J2.8, R7.2, U13.24 (~IP)
/FDC_RD: J2.30, R8.2, U13.19 (~RD)
/FDC_STEP: U13.16 (STEP), U15.9
/FDC_T0: J2.26, R10.2, U13.23 (~TR00)
/FDC_WD: U13.22 (WD), U15.13
/FDC_WG: U13.21 (WG), U15.3
/FDC_WPRT: J2.28, R9.2, U13.25 (~WPRT)
/GAL2_P9: D4.2 (A), U2.9 (I9), U3.6
/GAL2_P11: C2.2, D4.1 (K), R4.1, U2.11 (I10/~OE)
/GAL2_P15: D5.1 (K), U2.15 (IO5), U3.4
/GATE_WR: J2.24, U15.4
/HEAD: J2.32, U17.3 (~Q0)
/MA0: U5.4 (Za), U7.6 (A0), U8.6 (A0), U9.6 (A0), U10.6 (A0), U11.6 (A0), U12.6 (A0)
/MA1: U5.7 (Zb), U7.7 (A1), U8.7 (A1), U9.7 (A1), U10.7 (A1), U11.7 (A1), U12.7 (A1)
/MA2: U6.4 (Za), U7.8 (A2), U8.8 (A2), U9.8 (A2), U10.8 (A2), U11.8 (A2), U12.8 (A2)
/MA3: U6.7 (Zb), U7.9 (A3), U8.9 (A3), U9.9 (A3), U10.9 (A3), U11.9 (A3), U12.9 (A3)
/MA4: U6.9 (Zc), U7.11 (A4), U8.11 (A4), U9.11 (A4), U10.11 (A4), U11.11 (A4), U12.11 (A4)
/MA5: U6.12 (Zd), U7.12 (A5), U8.12 (A5), U9.12 (A5), U10.12 (A5), U11.12 (A5), U12.12 (A5)
/MA6: U5.9 (Zc), U7.13 (A6), U8.13 (A6), U9.13 (A6), U10.13 (A6), U11.13 (A6), U12.13 (A6)
/MA7: U5.12 (Zd), U7.14 (A7), U8.14 (A7), U9.14 (A7), U10.14 (A7), U11.14 (A7), U12.14 (A7)
/MA8: U1.15 (IO5), U7.15 (A8), U8.15 (A8), U9.15 (A8), U10.15 (A8), U11.15 (A8), U12.15 (A8)
/MOTOR_ON: J2.16, U17.11 (~Q2)
/MUX: D9.2 (A), U1.11 (I10/~OE), U2.13 (IO7), U3.2, U5.1 (S), U6.1 (S)
/RAS0: U2.19 (IO1), U11.4 (~RAS), U12.4 (~RAS)
/RAS1: U2.18 (IO2), U9.4 (~RAS), U10.4 (~RAS)
/RAS2: U2.17 (I03), U7.4 (~RAS), U8.4 (~RAS)
/RESET: J1.b21 (~RESETCPU), U1.7 (I7), U13.13 (~MR), U16.1 (~Mr), U17.1 (~Mr)
/ROM_CE: D8.1 (K), U1.19 (IO1), U14.20 (~CE)
/ROM_OE: U3.8, U14.22 (~OE)
/RW: J1.b26 (~DRW), U3.9, U7.3 (~WR), U8.3 (~WR), U9.3 (~WR), U10.3 (~WR), U11.3 (~WR), U12.3 (~WR), U13.2 (R/~W)
/SP0: J1.a4 (SP0)
/SP1: J1.a5 (SP1)
/SP2: J1.a7 (SP2)
/SP3: J1.b7 (SP3)
/STEP: J2.20, U15.8
/VPA: J1.b17 (~VPA)
GND: C1.2, C2.1, C3.2, C4.1, C5.2, C10.1, C12.2, C13.2, C14.2, C15.2, C16.2, C17.2, C18.2, C19.1, C20.2, C21.1, C22.2, C23.2, C24.2, C25.2, J1.a32 (GND), J1.b32 (GND), J2.1, J2.3, J2.5, J2.7, J2.9, J2.11, J2.13, J2.15, J2.17, J2.19, J2.21, J2.23, J2.25, J2.27, J2.29, J2.31, J2.33, J3.1, J4.1, R2.2, R4.2, U1.10 (GND), U2.10 (GND), U3.7 (GND), U4.8 (VSS), U4.11 (Reset), U5.8 (GND), U5.15 (E), U6.8 (GND), U6.15 (E), U7.16 (~OE), U7.20 (GND), U8.16 (~OE), U8.20 (GND), U9.16 (~OE), U9.20 (GND), U10.16 (~OE), U10.20 (GND), U11.16 (~OE), U11.20 (GND), U12.16 (~OE), U12.20 (GND), U13.14 (GND), U13.26 (~DDEN), U14.14 (GND), U15.7 (GND), U16.8 (GND), U17.8 (GND), U18.2 (GND)
unnamed: D1.2 (A), U1.12 (IO8)
unnamed: D2.1 (K), U2.16 (IO4)
unnamed: D3.1 (K), U2.14 (IO6)
unnamed: C3.1, D5.2 (A), R1.2, U3.5
unnamed: C4.2, D9.1 (K), R2.1, U3.3
unnamed: C5.1, D10.2 (A), R3.2, U3.1
unnamed: R5.1, R6.2, U3.11, U3.12
unnamed: R6.1, U3.13, Y1.2
unnamed: U1.13 (IO7), U2.1 (I1/CLK)
unnamed: U2.6 (I6), U4.6 (Q2)
unnamed: U2.7 (I7), U4.7 (Q1)
unnamed: U2.8 (I8), U4.9 (Q0)

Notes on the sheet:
(T1)
NOTE: C1,C10,C12,C15,C17 to C22 to C10 is in some photos 100nF (104 disc or yellow) and in another 330nF (330n blue) value is not critical. C14,C16,C23-C25 are also no critical, and size shall be checked as can conflict with memory chips and 7805, consider use 33uF/25V for C14 U14 is originally a 3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
MOTOR 0
BANK for 512,768
(T2)
DS0
DS1
READY / Disc Chan.
MOTOR 1
U16 - 74LS175 is optional and only need for a 3rd and 4rd Disk Drive
For no RAM version, replace D5, D9 and D10 by wires, or 0ohm resistors
Componentes below this line only need for RAM modules
N/C
(T3)
Only Install for with RAM chips
BANK for 768, ACE
DENSITY SEL
BANK for 256, 512,768

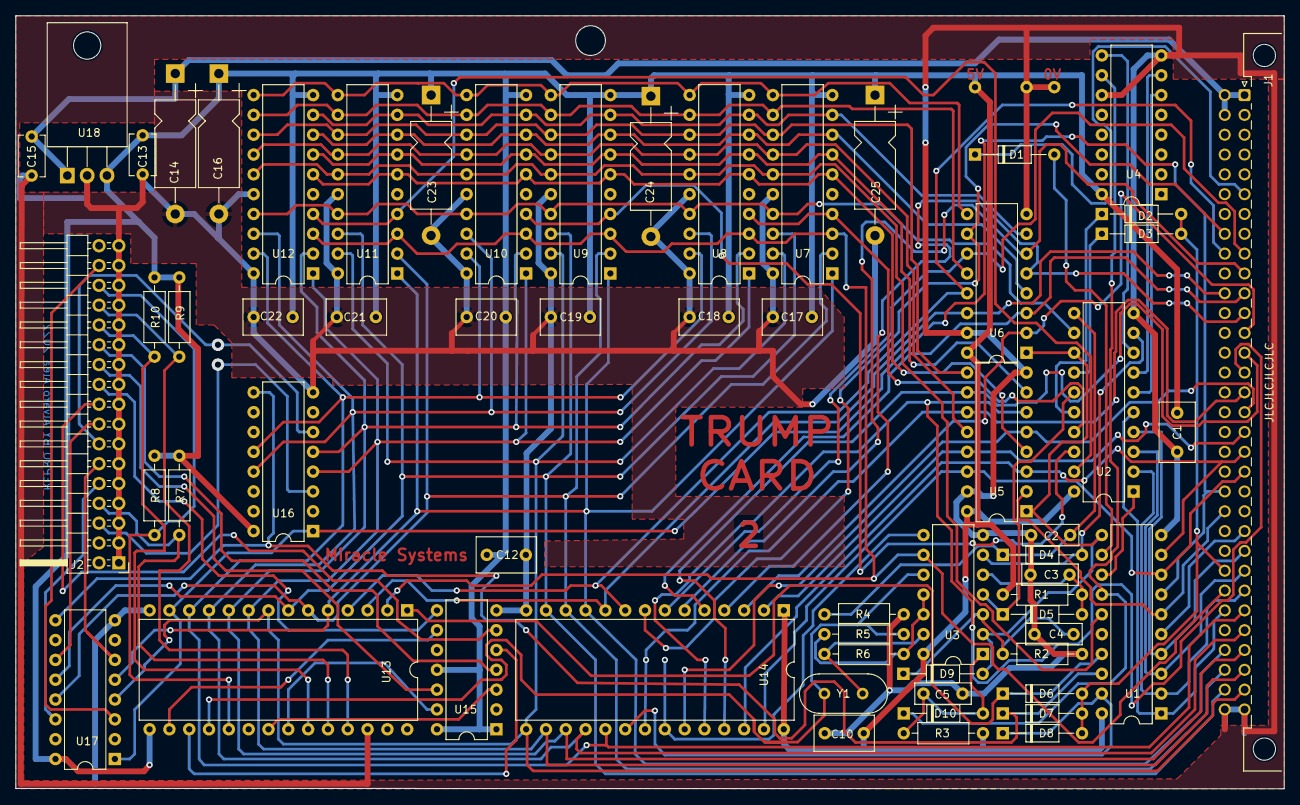
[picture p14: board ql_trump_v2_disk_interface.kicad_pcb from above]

Board: 2 copper layers, 162.6 x 99.1 mm, 64 parts (0 on the bottom side), 89 nets.

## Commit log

2022-10-01 ínicial
    [ql_trump_v2_disk_interface-B_Cu.gbr, ql_trump_v2_disk_interface-B_Mask.gbr, ql_trump_v2_disk_interface-B_Silkscreen.gbr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]
2024-05-08 solucionada chapuza
    [ql_trump_v2_disk_interface-B_Cu.gbr, ql_trump_v2_disk_interface-B_Mask.gbr, ql_trump_v2_disk_interface-B_Silkscreen.gbr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]
2024-07-26 update BOM and gervers
    [ql_trump_v2_disk_interface-B_Cu.gbr, ql_trump_v2_disk_interface-B_Mask.gbr, ql_trump_v2_disk_interface-B_Silks.gbr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]
2024-08-13 fix ROM reference
    [ql_trump_v2_disk_interface.kicad_pcb, ql_trump_v2_disk_interface.kicad_sch]
2024-11-11 some updated on GALs
    [ql_trump_v2_disk_interface-B_Cu.gbr, ql_trump_v2_disk_interface-B_Mask.gbr, ql_trump_v2_disk_interface-B_Silks.gbr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]
2024-11-22 minor typos
    [ql_trump_v2_disk_interface-B_Cu.gbr, ql_trump_v2_disk_interface-B_Mask.gbr, ql_trump_v2_disk_interface-B_Paste.gbp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]
